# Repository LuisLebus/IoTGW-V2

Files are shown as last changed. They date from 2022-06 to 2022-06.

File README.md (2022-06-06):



<!-- LOGO AND TITTLE -->
<div align="center">
  <h3 align="center">Luis Lebus</h3>

  [][linkedin-url]
  [][portfolio-url]
  
  <br>
  
  <h3 align="center">IoTGW-V2</h3>
  <p align="center">Gateway IoT V2</p>
</div>

<!-- TABLE OF CONTENTS -->
<details>
  <summary>Table of Contents</summary>
  <ol>
    <li>
      <a href="#description">Description</a>
      <ul>
        <li><a href="#built-with">Built With</a></li>
      </ul>
    </li>
    <li><a href="#image">Image</a></li>
    <li><a href="#contact">Contact</a></li>
    <li><a href="#acknowledgments">Acknowledgments</a></li>
  </ol>
</details>

<!-- ABOUT THE PROJECT -->
## Description

This project is an IoT gateway. 
<br>
This board has CAN, Modbus RTU, WiFi and Ethernet communication.

<p align="right">(<a href="#top">back to top</a>)</p>

### Built With

* [KiCad v5.1.12](https://www.kicad.org/)

<p align="right">(<a href="#top">back to top</a>)</p>

<!-- ABOUT THE PROJECT -->
## Image

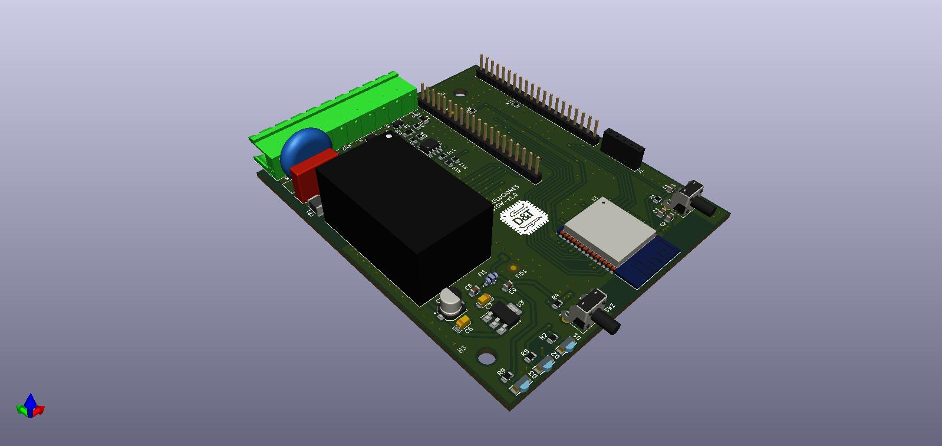
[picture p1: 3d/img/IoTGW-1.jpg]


<p align="right">(<a href="#top">back to top</a>)</p>

<!-- CONTACT -->
## Contact

Luis Lebus - luislebus@gmail.com

* [LinkedIn](https://www.linkedin.com/in/LuisLebus)
* [Portfolio](https://luislebus.github.io/portfolio)

<p align="right">(<a href="#top">back to top</a>)</p>

<!-- ACKNOWLEDGMENTS -->
## Acknowledgments

<p align="right">(<a href="#top">back to top</a>)</p>

<!-- MARKDOWN LINKS & IMAGES -->
[linkedin-shield]: https://img.shields.io/badge/LinkedIn-0077B5?style=for-the-badge&logo=linkedin&logoColor=white
[linkedin-url]: https://www.linkedin.com/in/LuisLebus
[portfolio-shield]: https://img.shields.io/badge/PORTFOLIO%20-%23323330.svg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
[portfolio-url]: https://luislebus.github.io/portfolio

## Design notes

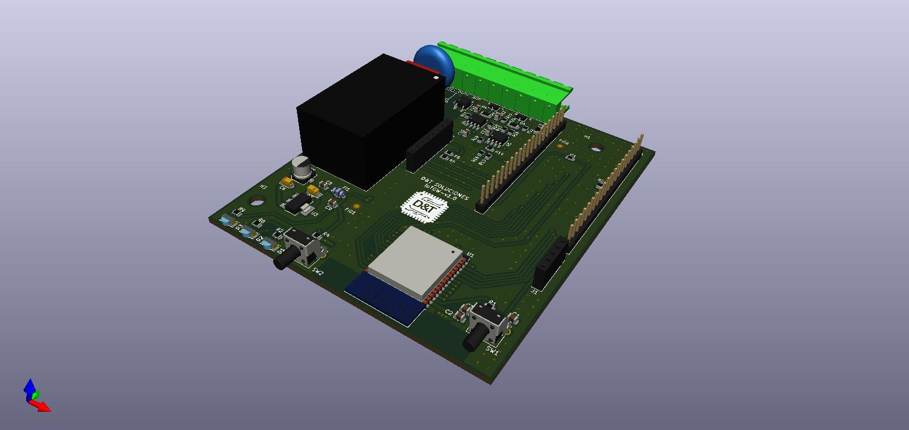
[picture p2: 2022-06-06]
3d/img/IoTGW-2.jpg

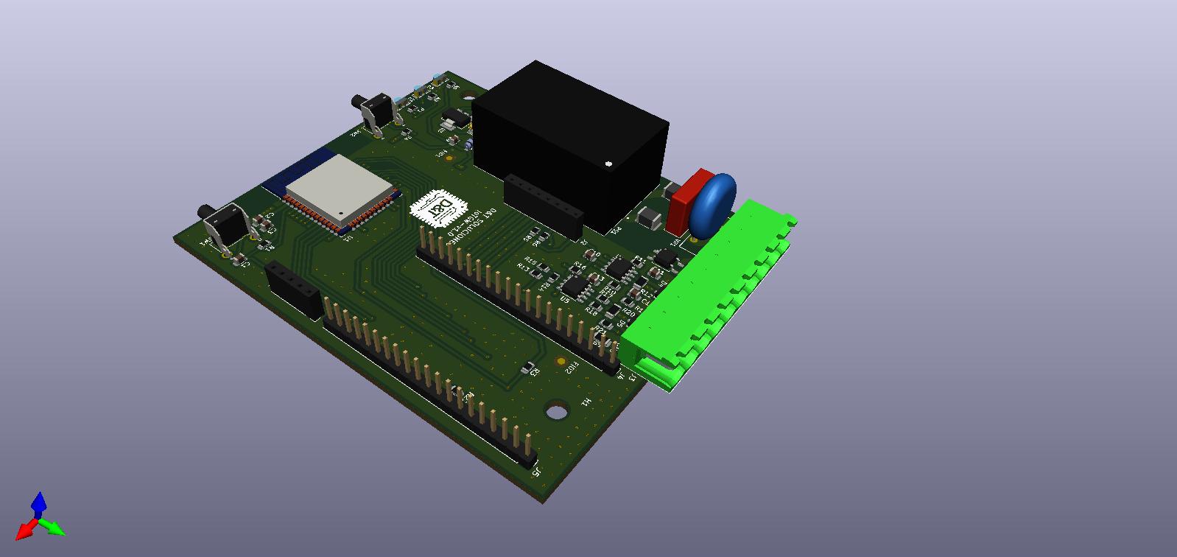
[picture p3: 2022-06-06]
3d/img/IoTGW-3.jpg

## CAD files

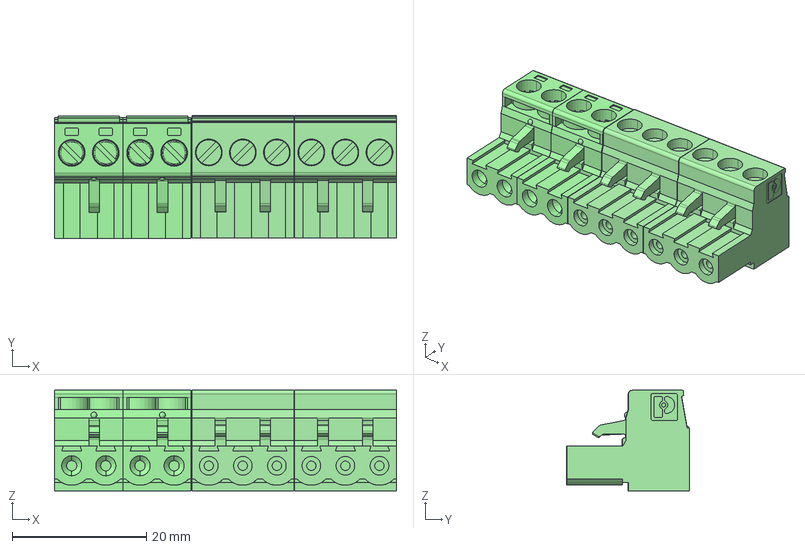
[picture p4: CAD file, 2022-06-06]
3d/IoTGW.FCStd
51.0 x 18.4 x 15.0 mm
MSTB-2.5-Clamp-sleeve
MSTB-2.5-GEH
MSTB-2.5-Clamp-sleeve001
MSTB_2.5_3-ST-5.08
MSTB-2.5-Clamp-sleeve002
MSTB-2.5-GEH001
MSTB-2.5-Clamp-sleeve003
MSTB_2.5_3-ST-5.010

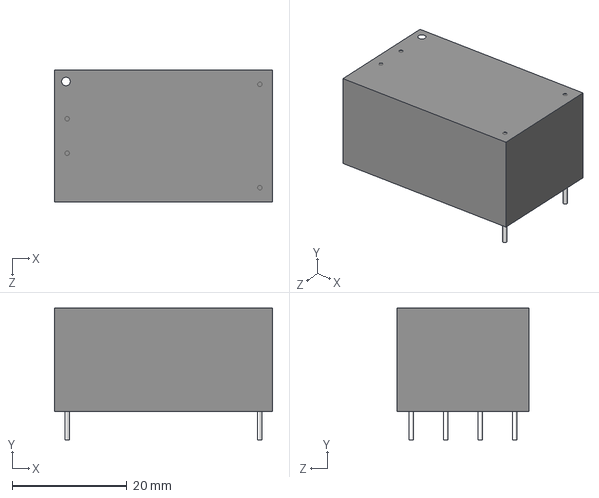
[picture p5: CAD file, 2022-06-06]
user-libraries/user-packages3d/HLK-5M05.STEP
38.0 x 23.0 x 23.0 mm

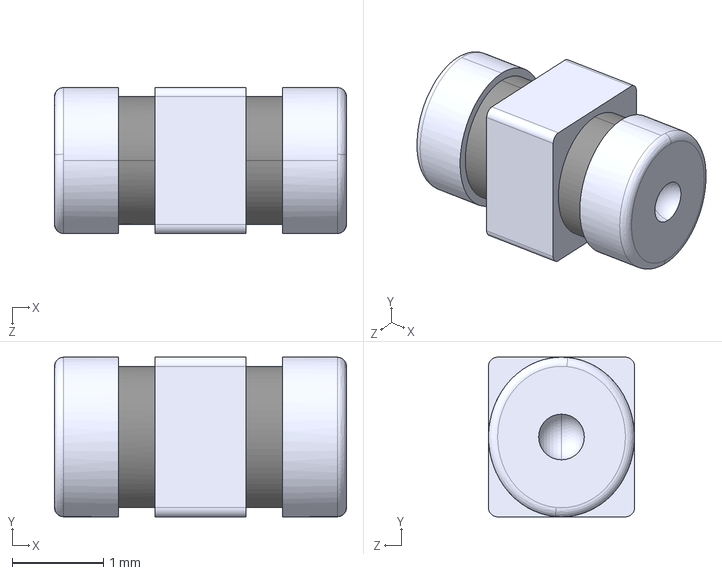
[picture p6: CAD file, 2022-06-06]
user-libraries/user-packages3d/NFE31PT222Z1E9L.STEP
3.20 x 1.75 x 1.60 mm

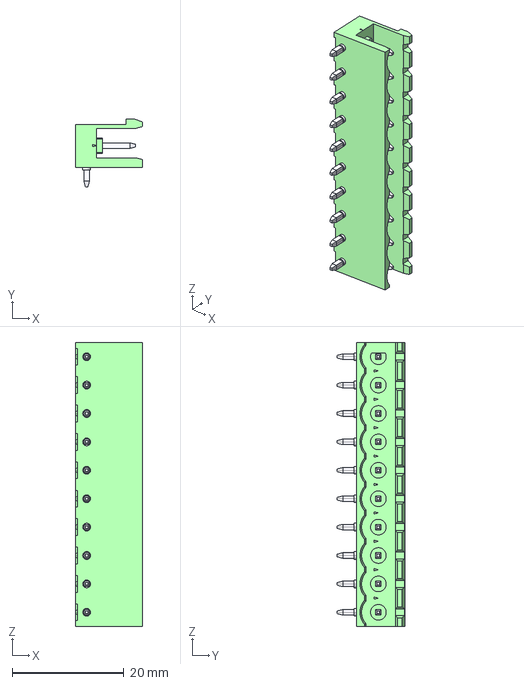
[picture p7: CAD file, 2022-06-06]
user-libraries/user-packages3d/1759091.stp
12.0 x 12.1 x 50.8 mm

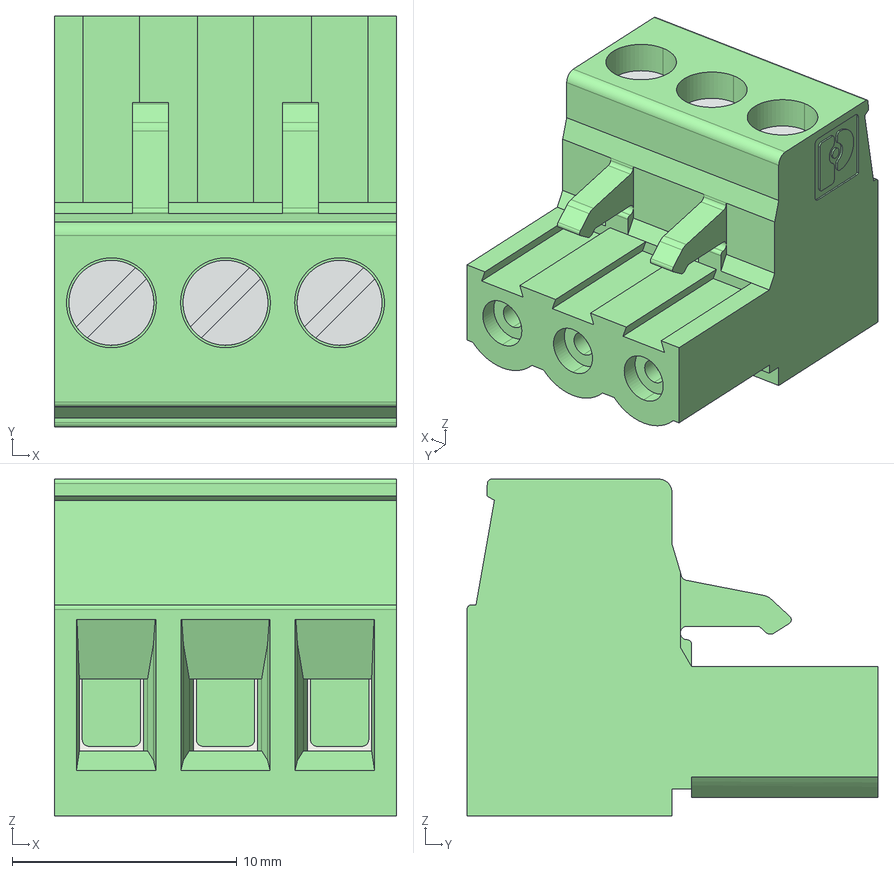
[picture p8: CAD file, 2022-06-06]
3d/1757022.stp
15.2 x 18.3 x 15.0 mm

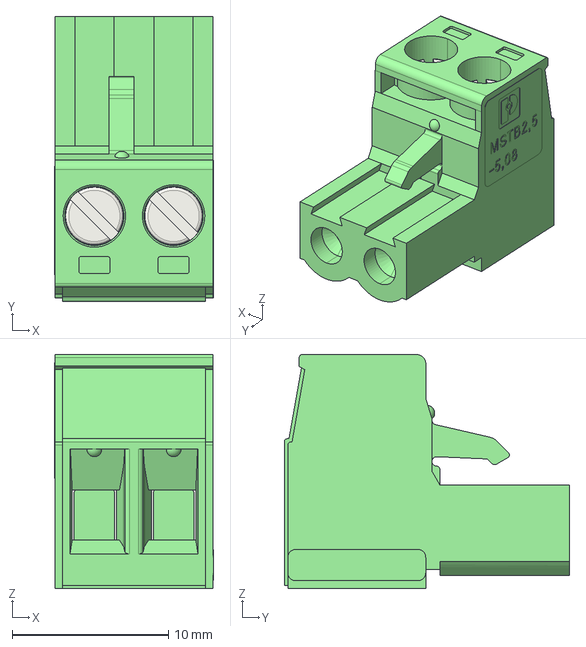
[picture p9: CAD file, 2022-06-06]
3d/1757019.stp
10.2 x 18.3 x 15.0 mm
MSTB-2.5-Clamp-sleeve x 2
MSTB-2.5-GEH

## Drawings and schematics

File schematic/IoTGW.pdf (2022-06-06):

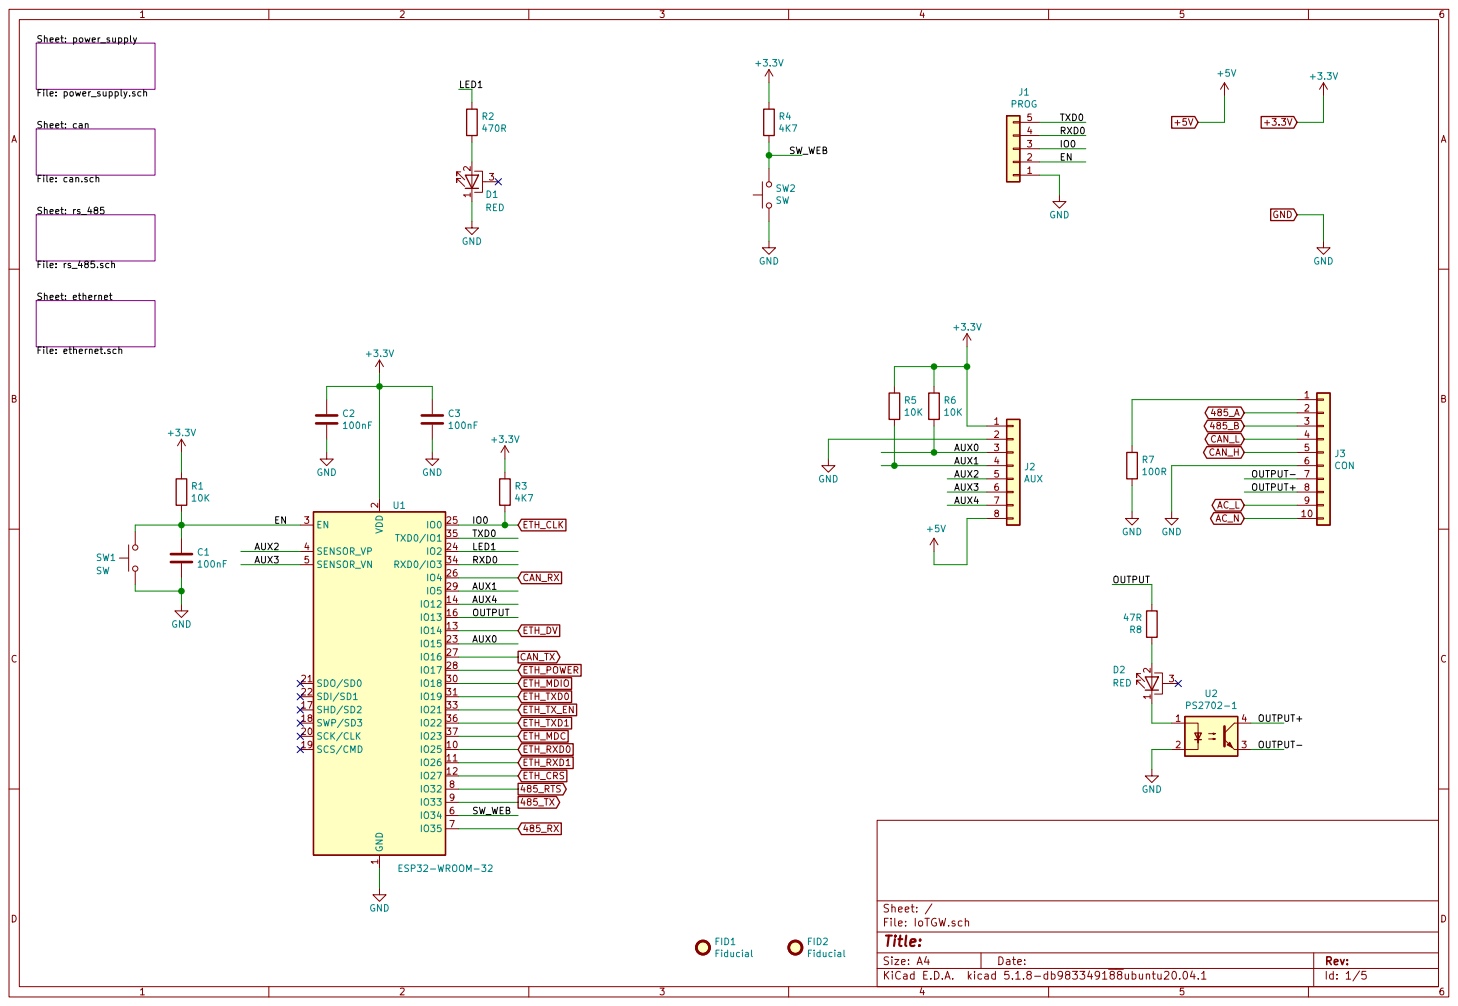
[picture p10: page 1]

File: power_supply.sch Sheet: can File: can.sch Sheet: rs_485 File: rs_485.sch Sheet: ethernet File: ethernet.sch

2 SCK/CLK 20 SDO/SD0 21 SDI/SD1 22

Id: 1/5 Title: File: IoTGW.sch Sheet: /

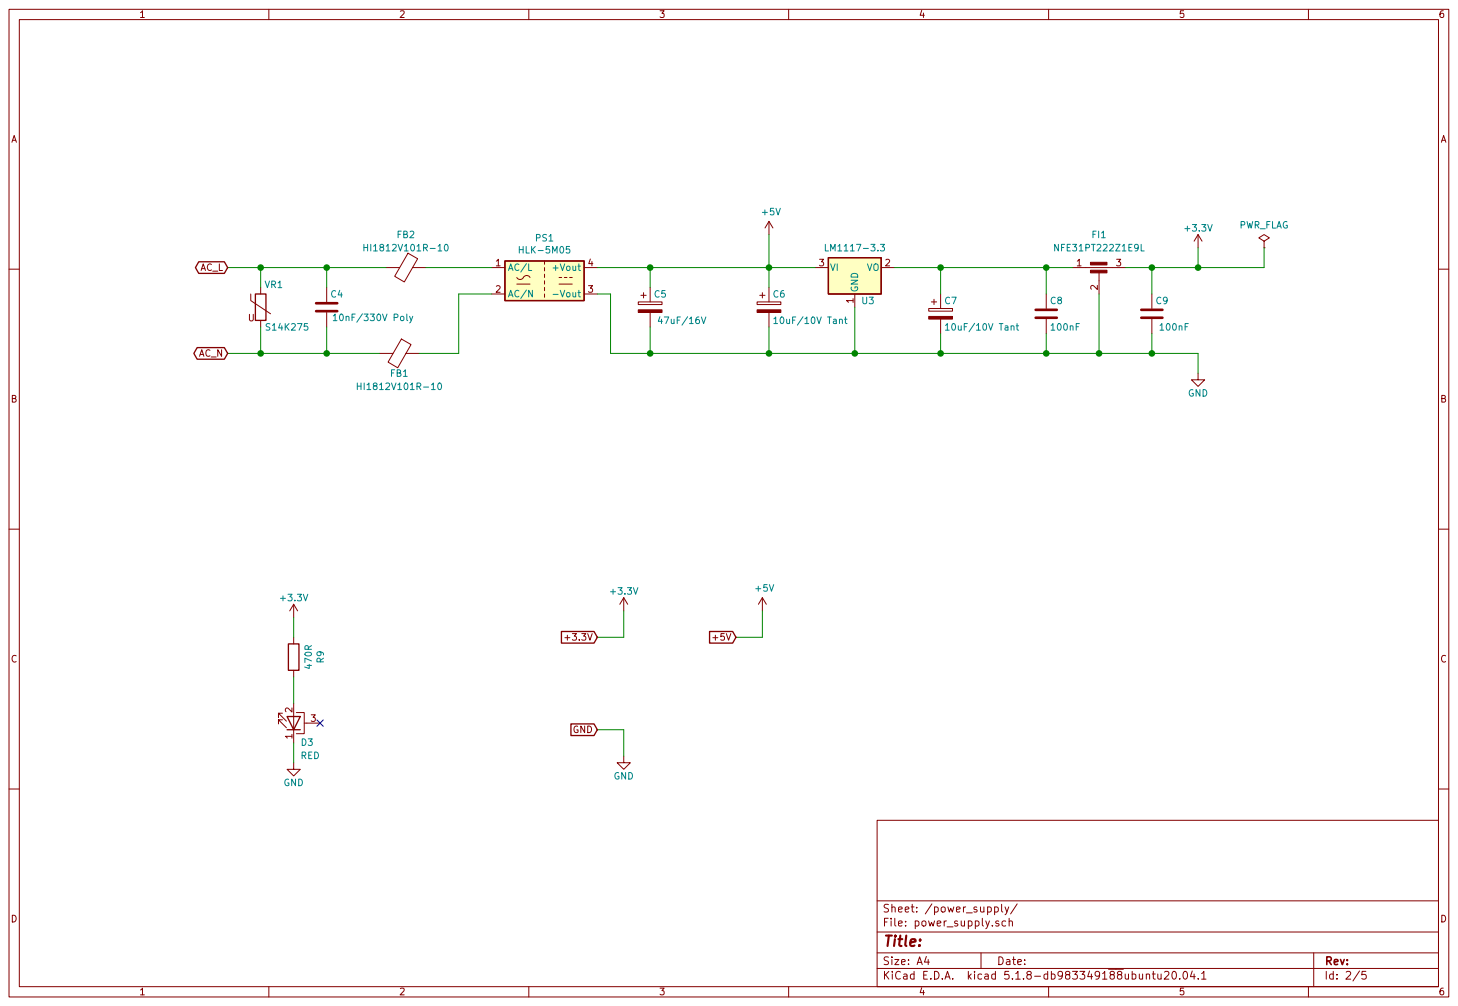
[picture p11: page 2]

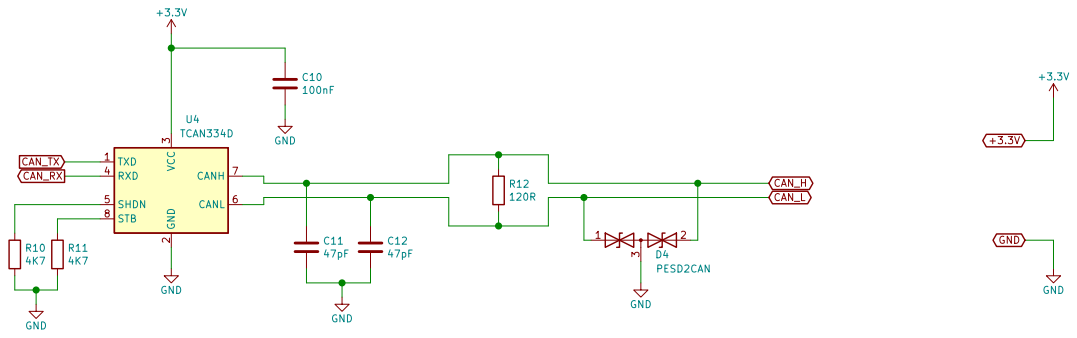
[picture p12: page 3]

3 RXD 4 SHDN 5 CANL 6 CANH 7 STB 8 U4 TCAN334D

Id: 3/5 Title: File: can.sch Sheet: /can/ GND

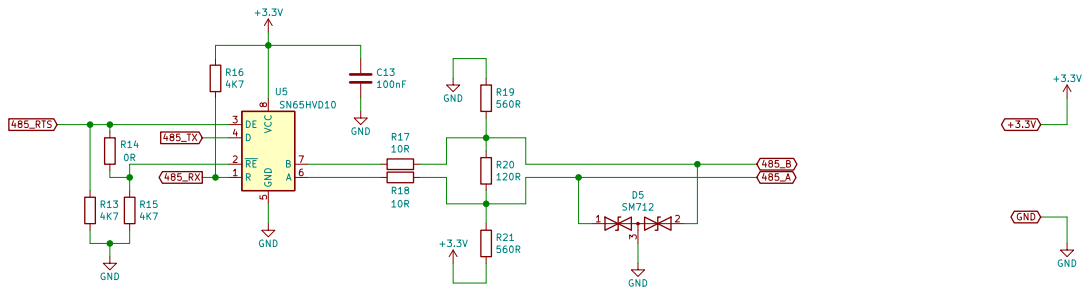
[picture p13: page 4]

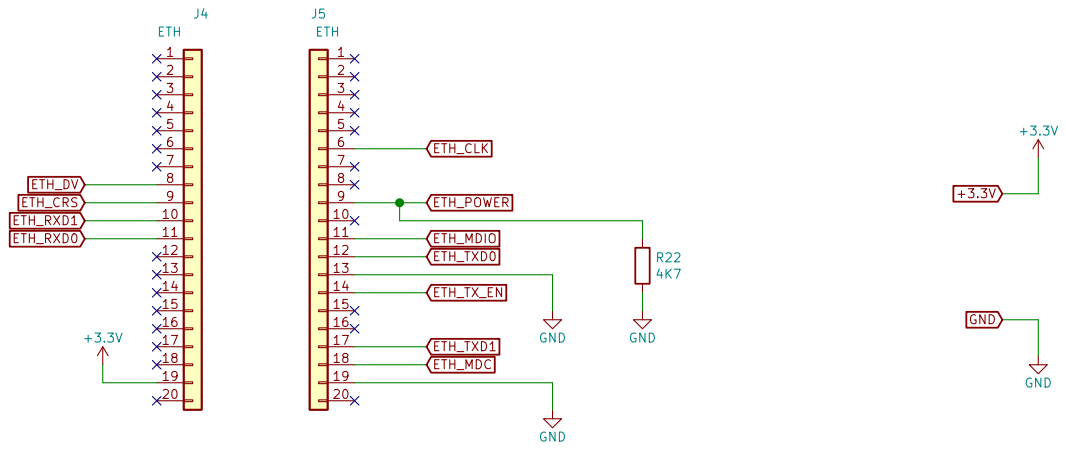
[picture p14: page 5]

Id: 5/5 Title: File: ethernet.sch Sheet: /ethernet/ GND

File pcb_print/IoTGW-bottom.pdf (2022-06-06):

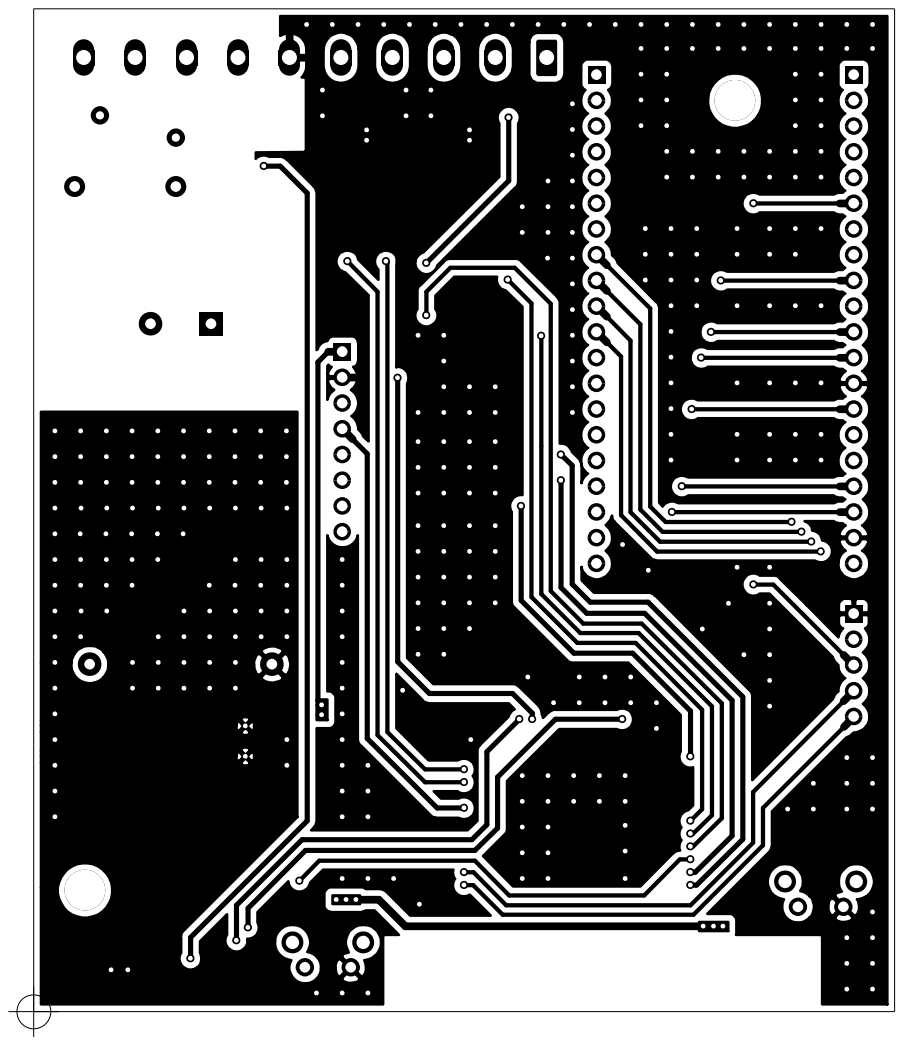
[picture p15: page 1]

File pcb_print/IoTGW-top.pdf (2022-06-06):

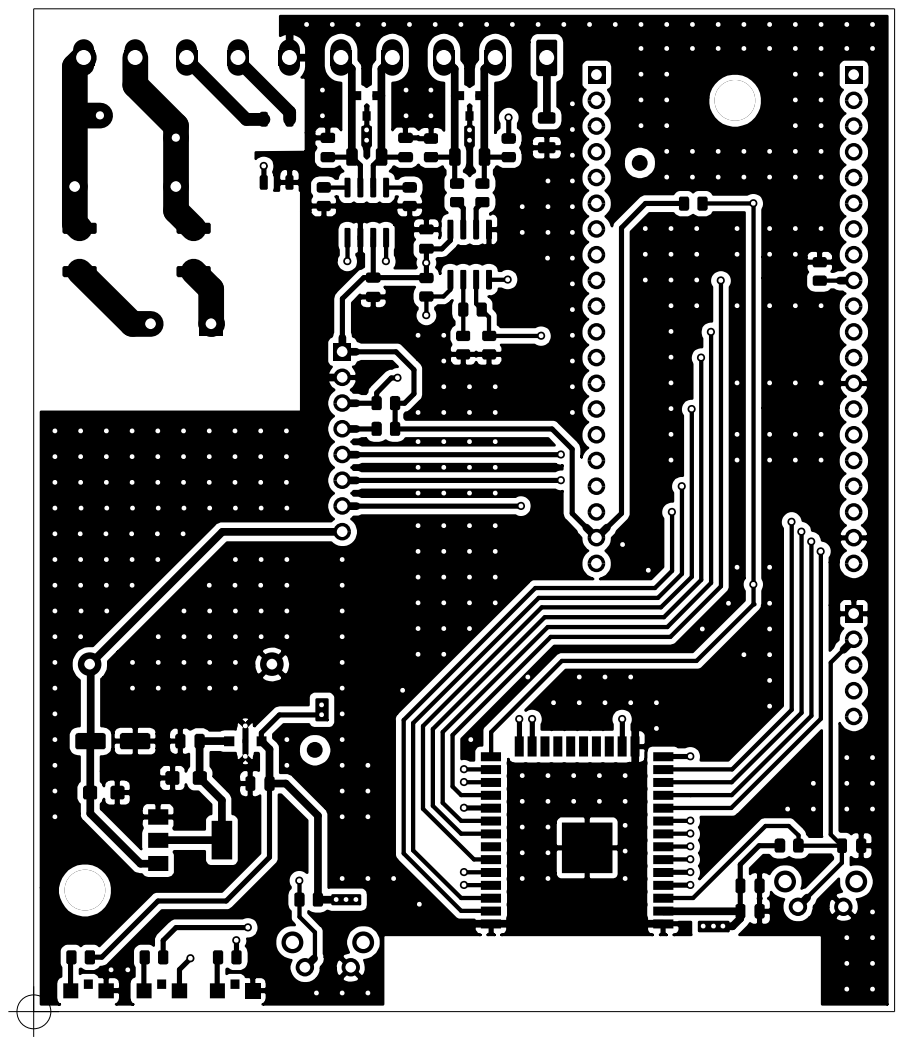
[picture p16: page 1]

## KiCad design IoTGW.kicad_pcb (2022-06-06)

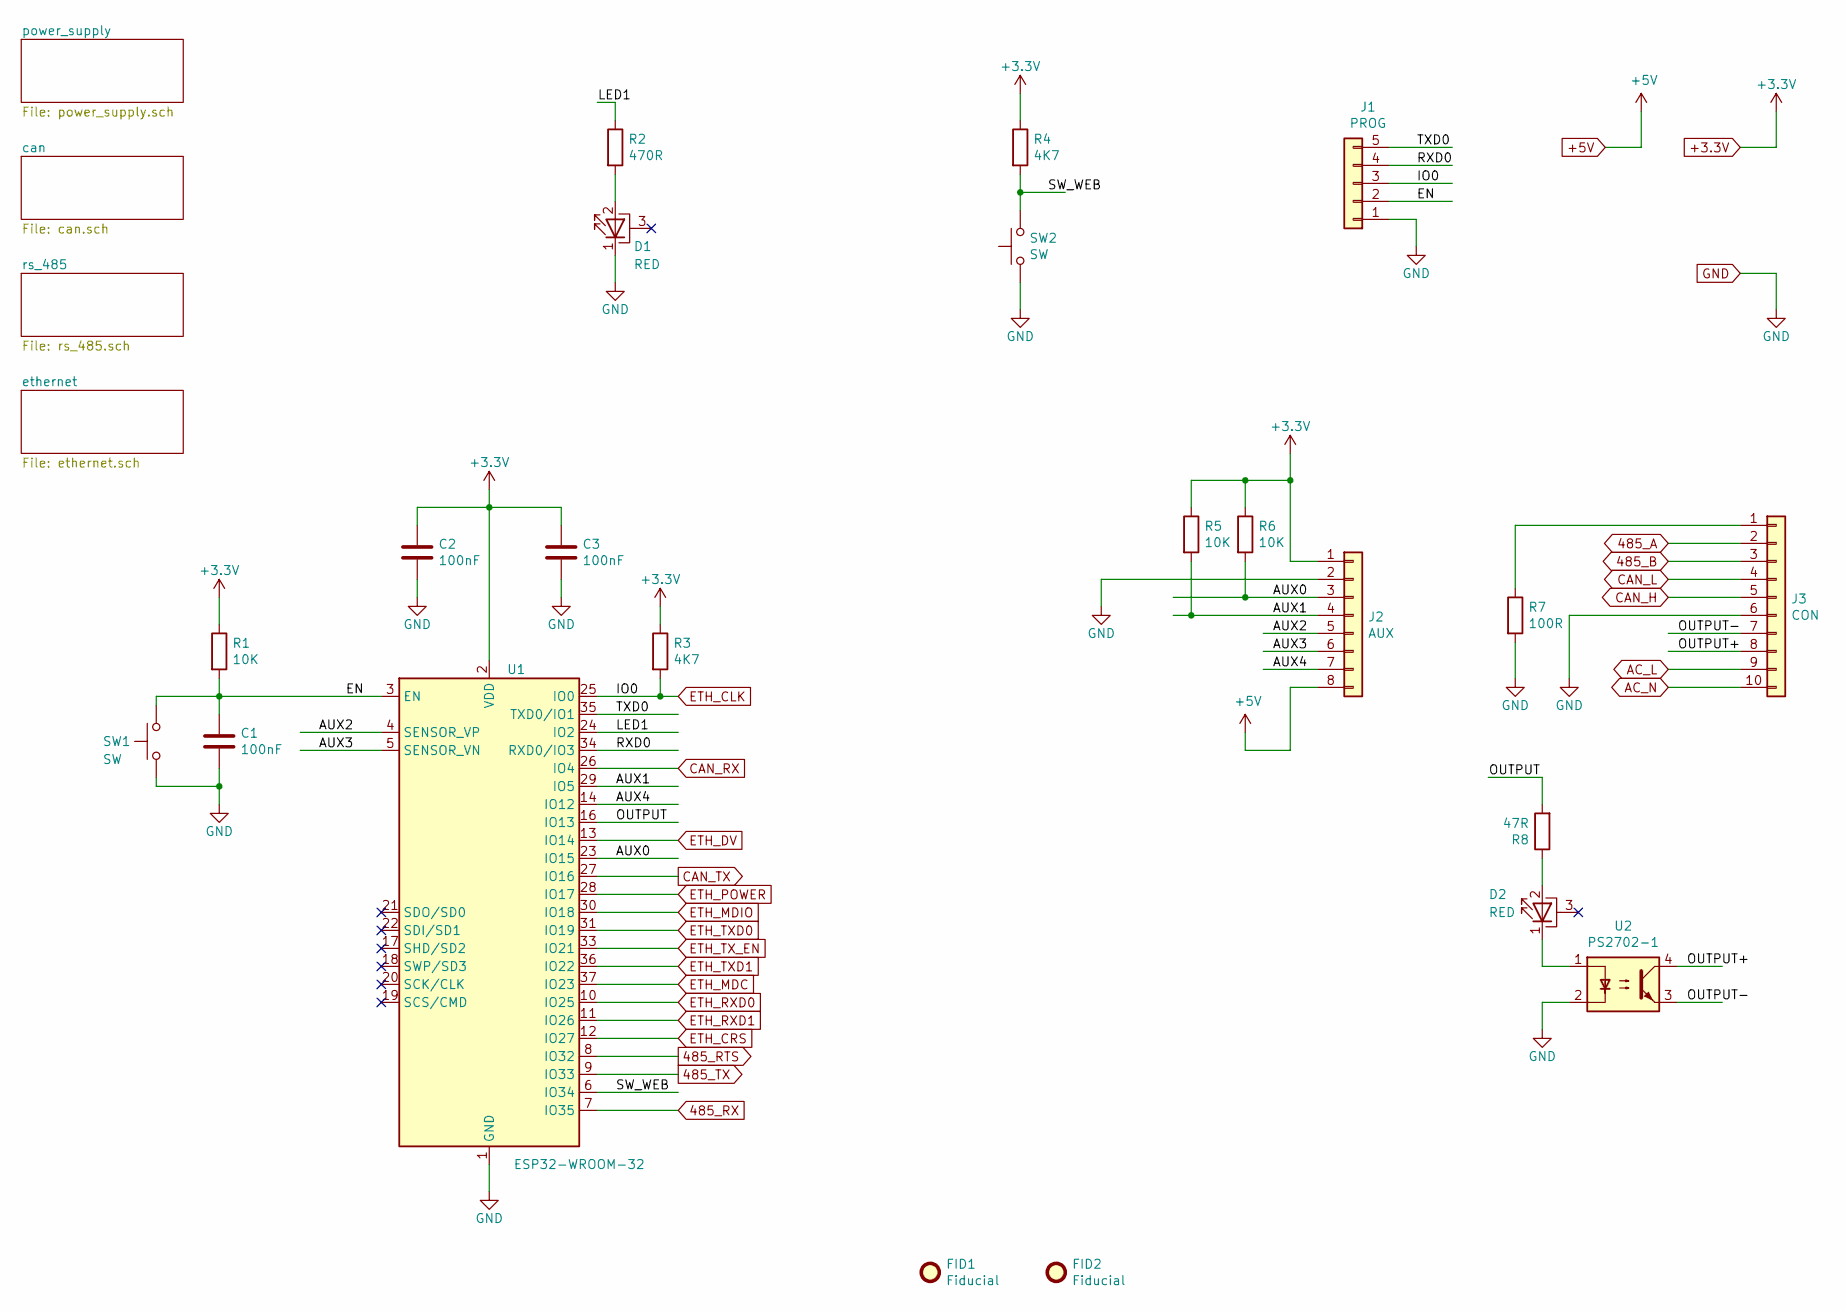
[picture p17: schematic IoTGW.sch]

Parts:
C1, C2, C3: 100nF; C_0805_2012Metric
D1, D2: RED; LTST-S321KRKT
FID1, FID2: Fiducial; Fiducial_1.5mm_Mask3mm
J1: PROG; PinSocket_1x05_P2.54mm_Vertical
J2: AUX; PinSocket_1x08_P2.54mm_Vertical
J3: CON; 1759091
R1, R5, R6: 10K; R_0805_2012Metric
R2: 470R; R_0805_2012Metric
R3, R4: 4K7; R_0805_2012Metric
R7: 100R; R_1206_3216Metric
R8: 47R; R_0805_2012Metric
SW1, SW2: SW; SW_Tactile_SPST_Angled_PTS645Vx83-2LFS
U1: ESP32-WROOM-32
U2: PS2702-1; PS2702-1-F3-K-A

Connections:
485_A: J3.2; also elsewhere on the board
485_B: J3.3; also elsewhere on the board
485_RTS: U1.8 (IO32); also elsewhere on the board
485_RX: U1.7 (IO35); also elsewhere on the board
485_TX: U1.9 (IO33); also elsewhere on the board
+3.3V: C2.1, C3.1, J2.1, R1.1, R3.1, R4.1, R5.1, R6.1, U1.2 (VDD); also elsewhere on the board
+5V: J2.8; also elsewhere on the board
/AUX0: J2.3, R6.2, U1.23 (IO15)
/AUX1: J2.4, R5.2, U1.29 (IO5)
/AUX2: J2.5, U1.4 (SENSOR_VP)
/AUX3: J2.6, U1.5 (SENSOR_VN)
/AUX4: J2.7, U1.14 (IO12)
/EN: C1.1, J1.2, R1.2, SW1.2, U1.3 (EN)
/LED1: R2.1, U1.24 (IO2)
/OUTPUT: R8.2, U1.16 (IO13)
/OUTPUT+: J3.8, U2.4
/OUTPUT-: J3.7, U2.3
/RXD0: J1.4, U1.34 (RXD0/IO3)
/SW_WEB: R4.2, SW2.2, U1.6 (IO34)
/TXD0: J1.5, U1.35 (TXD0/IO1)
AC_L: J3.9; also elsewhere on the board
AC_N: J3.10; also elsewhere on the board
CAN_H: J3.5; also elsewhere on the board
CAN_L: J3.4; also elsewhere on the board
CAN_RX: U1.26 (IO4); also elsewhere on the board
CAN_TX: U1.27 (IO16); also elsewhere on the board
ETH_CLK: J1.3, R3.2, U1.25 (IO0); also elsewhere on the board
ETH_CRS: U1.12 (IO27); also elsewhere on the board
ETH_DV: U1.13 (IO14); also elsewhere on the board
ETH_MDC: U1.37 (IO23); also elsewhere on the board
ETH_MDIO: U1.30 (IO18); also elsewhere on the board
ETH_POWER: U1.28 (IO17); also elsewhere on the board
ETH_RXD0: U1.10 (IO25); also elsewhere on the board
ETH_RXD1: U1.11 (IO26); also elsewhere on the board
ETH_TXD0: U1.31 (IO19); also elsewhere on the board
ETH_TXD1: U1.36 (IO22); also elsewhere on the board
ETH_TX_EN: U1.33 (IO21); also elsewhere on the board
GND: C1.2, C2.2, C3.2, D1.1 (K), J1.1, J2.2, J3.6, R7.2, SW1.1, SW2.1, U1.1 (GND), U1.15 (GND), U1.38 (GND), U1.39 (GND), U2.2; also elsewhere on the board
unnamed: D1.2 (A), R2.2
unnamed: D2.1 (K), U2.1
unnamed: D2.2 (A), R8.1
unnamed: J3.1, R7.1

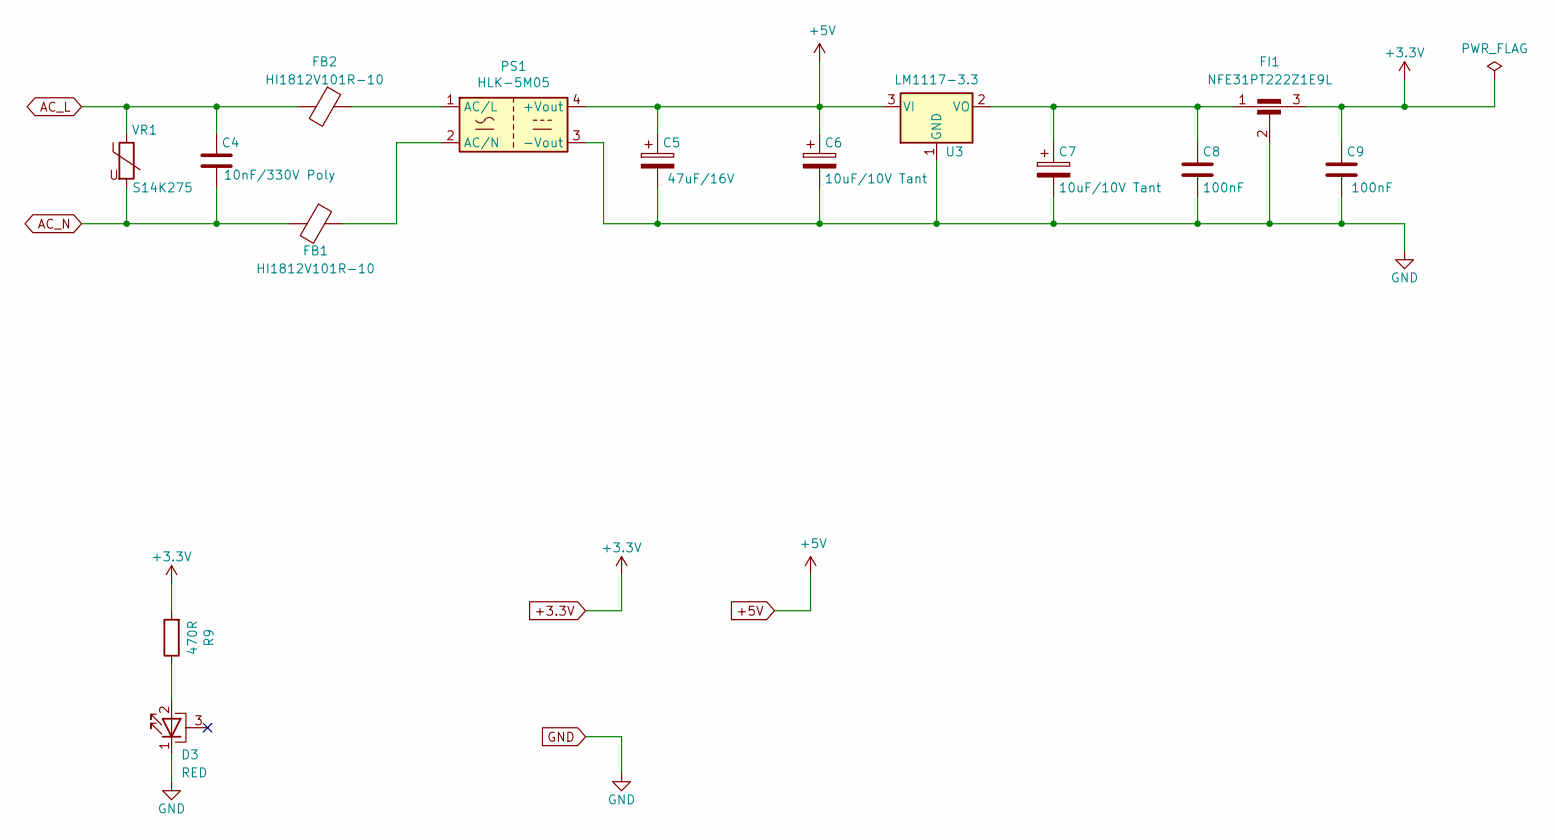
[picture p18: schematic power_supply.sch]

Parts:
C4: 10nF/330V Poly; C_Rect_L13.0mm_W4.0mm_P10.00mm_FKS3_FKP3_MKS4
C5: 47uF/16V; CP_Elec_5x5.4
C6, C7: 10uF/10V Tant; CP_EIA-3216-18_Kemet-A
C8, C9: 100nF; C_0805_2012Metric
D3: RED; LTST-S321KRKT
FB1, FB2: HI1812V101R-10; L_1812_4532Metric
FI1: NFE31PT222Z1E9L
PS1: HLK-5M05
R9: 470R; R_0805_2012Metric
U3: LM1117-3.3; SOT-223-3_TabPin2
VR1: S14K275; RV_Disc_D15.5mm_W5mm_P7.5mm

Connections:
+3.3V: C9.1, FI1.3, R9.2; also elsewhere on the board
+5V: C5.1, C6.1, PS1.4 (+Vout), U3.3 (VI); also elsewhere on the board
AC_L: C4.1, FB2.2, VR1.1; also elsewhere on the board
AC_N: C4.2, FB1.2, VR1.2; also elsewhere on the board
GND: C5.2, C6.2, C7.2, C8.2, C9.2, D3.1 (K), FI1.2, PS1.3 (-Vout), U3.1 (GND); also elsewhere on the board
unnamed: C7.1, C8.1, FI1.1, U3.2 (VO)
unnamed: D3.2 (A), R9.1
unnamed: FB1.1, PS1.2 (AC/N)
unnamed: FB2.1, PS1.1 (AC/L)

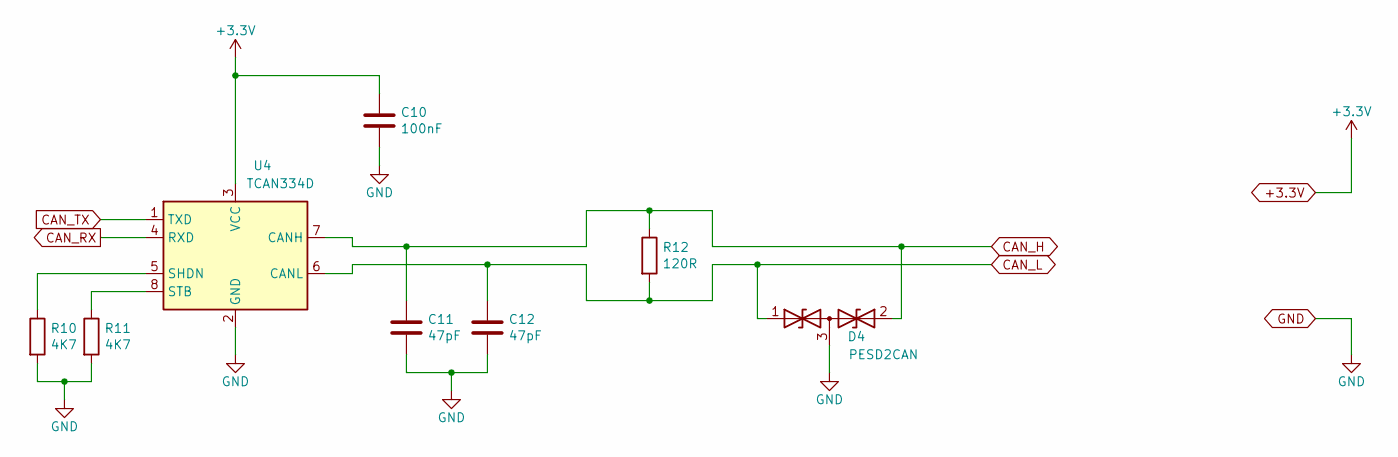
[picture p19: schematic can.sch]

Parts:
C10: 100nF; C_0805_2012Metric
C11, C12: 47pF; C_0805_2012Metric
D4: PESD2CAN; SOT-23
R10, R11: 4K7; R_0805_2012Metric
R12: 120R; R_1206_3216Metric
U4: TCAN334D; SOIC-8_3.9x4.9mm_P1.27mm

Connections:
+3.3V: C10.1, U4.3 (VCC); also elsewhere on the board
CAN_H: C11.1, D4.2 (A2), R12.1, U4.7 (CANH); also elsewhere on the board
CAN_L: C12.1, D4.1 (A1), R12.2, U4.6 (CANL); also elsewhere on the board
CAN_RX: U4.4 (RXD); also elsewhere on the board
CAN_TX: U4.1 (TXD); also elsewhere on the board
GND: C10.2, C11.2, C12.2, D4.3 (common), R10.2, R11.2, U4.2 (GND); also elsewhere on the board
unnamed: R10.1, U4.5 (SHDN)
unnamed: R11.1, U4.8 (STB)

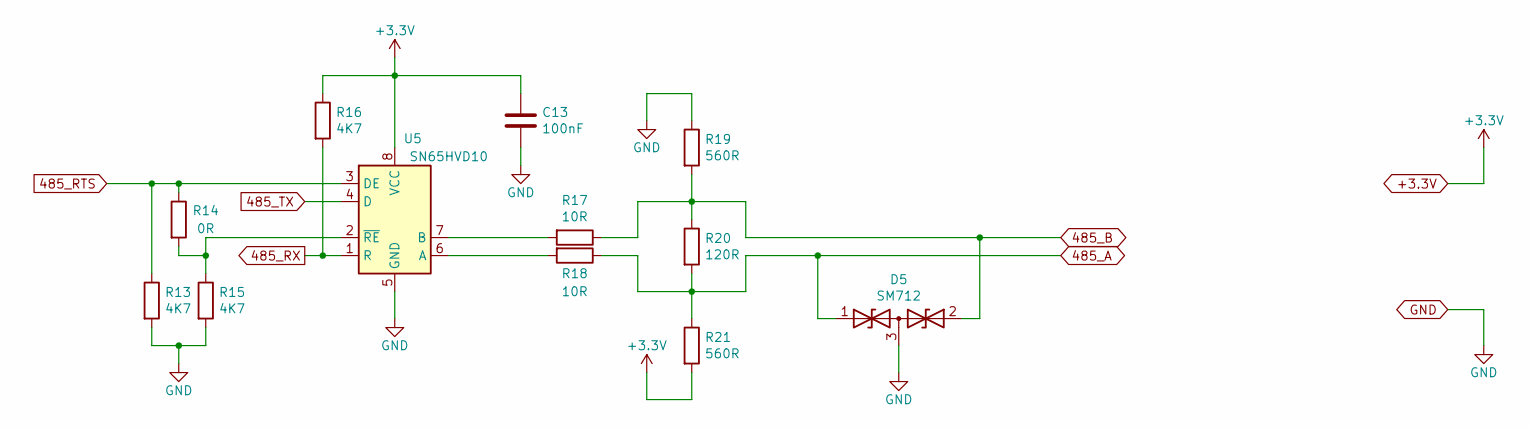
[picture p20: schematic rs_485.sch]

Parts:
C13: 100nF; C_0805_2012Metric
D5: SM712; SOT-23
R13, R15, R16: 4K7; R_0805_2012Metric
R14: 0R; R_0805_2012Metric
R17, R18: 10R; R_0805_2012Metric
R19, R21: 560R; R_0805_2012Metric
R20: 120R; R_1206_3216Metric
U5: SN65HVD10; SOIC-8_3.9x4.9mm_P1.27mm

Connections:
485_A: D5.1 (A1), R18.1, R20.2, R21.1; also elsewhere on the board
485_B: D5.2 (A2), R17.1, R19.2, R20.1; also elsewhere on the board
485_RTS: R13.1, R14.1, U5.3 (DE); also elsewhere on the board
485_RX: R16.2, U5.1 (R); also elsewhere on the board
485_TX: U5.4 (D); also elsewhere on the board
+3.3V: C13.1, R16.1, R21.2, U5.8 (VCC); also elsewhere on the board
GND: C13.2, D5.3 (common), R13.2, R15.2, R19.1, U5.5 (GND); also elsewhere on the board
unnamed: R14.2, R15.1, U5.2 (~RE)
unnamed: R17.2, U5.7 (B)
unnamed: R18.2, U5.6 (A)

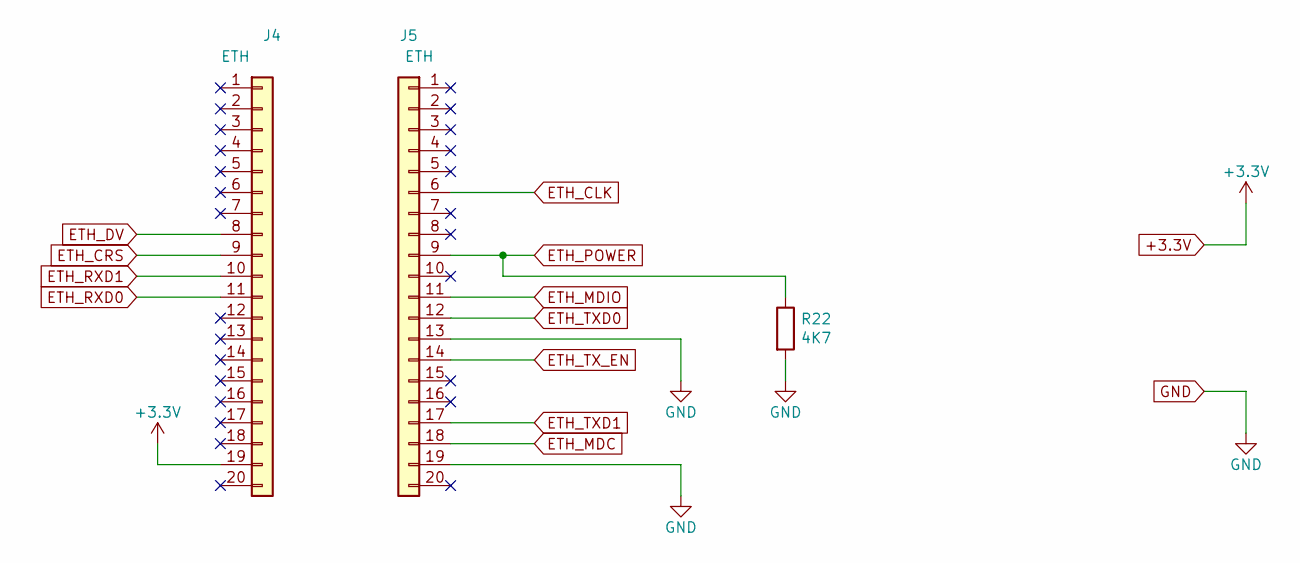
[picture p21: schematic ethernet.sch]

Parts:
J4, J5: ETH; PinHeader_1x20_P2.54mm_Vertical
R22: 4K7; R_0805_2012Metric

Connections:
+3.3V: J4.19; also elsewhere on the board
ETH_CLK: J5.6; also elsewhere on the board
ETH_CRS: J4.9; also elsewhere on the board
ETH_DV: J4.8; also elsewhere on the board
ETH_MDC: J5.18; also elsewhere on the board
ETH_MDIO: J5.11; also elsewhere on the board
ETH_POWER: J5.9, R22.1; also elsewhere on the board
ETH_RXD0: J4.11; also elsewhere on the board
ETH_RXD1: J4.10; also elsewhere on the board
ETH_TXD0: J5.12; also elsewhere on the board
ETH_TXD1: J5.17; also elsewhere on the board
ETH_TX_EN: J5.14; also elsewhere on the board
GND: J5.13, J5.19, R22.2; also elsewhere on the board

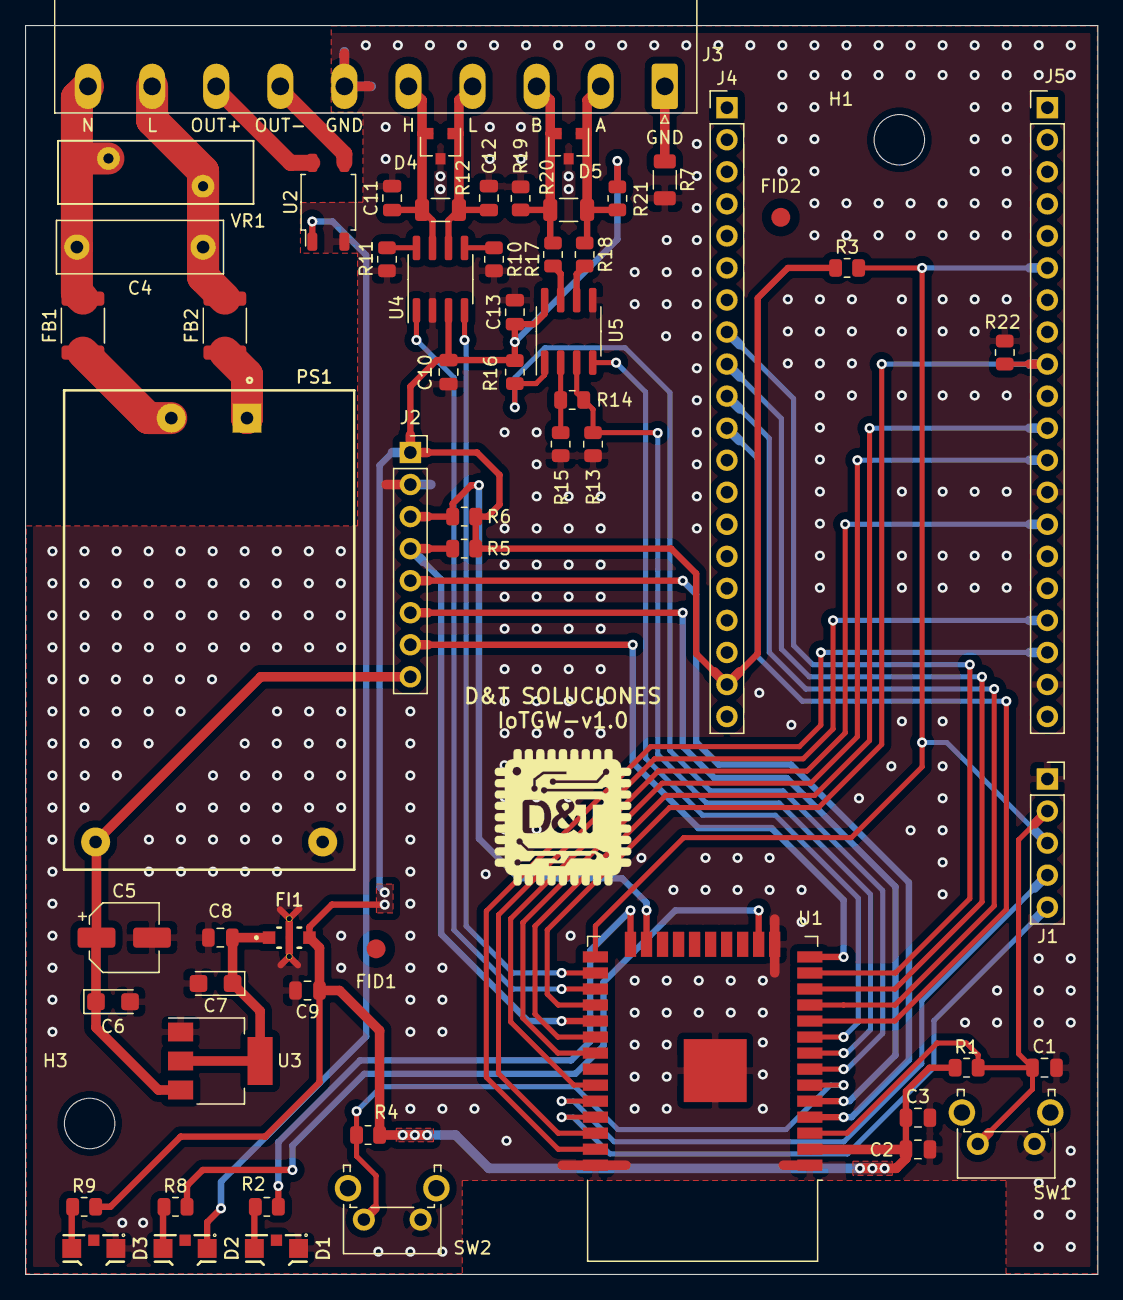
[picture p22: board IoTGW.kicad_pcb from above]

Board: 2 copper layers, 85.0 x 99.0 mm, 61 parts (0 on the bottom side), 51 nets.

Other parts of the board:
H1, H3: MountingHole_4mm
